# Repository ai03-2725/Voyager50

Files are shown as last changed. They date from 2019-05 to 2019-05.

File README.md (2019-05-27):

# Voyager50
A balance between function and size

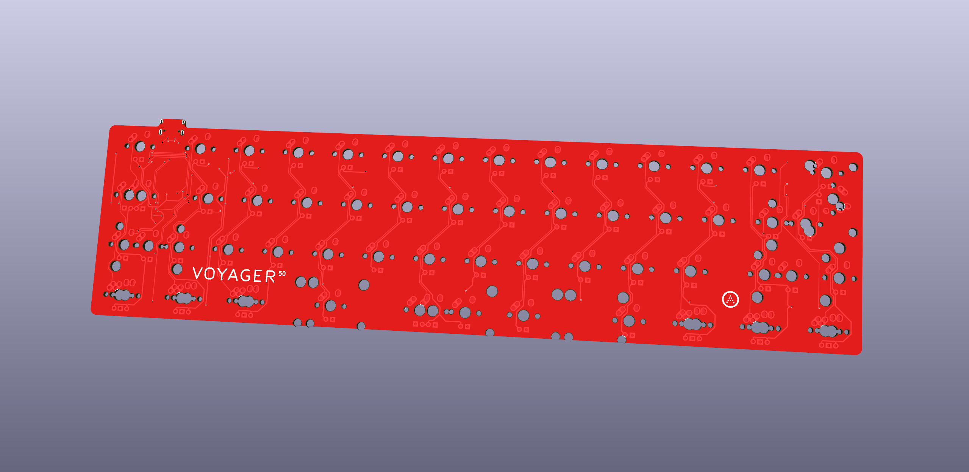
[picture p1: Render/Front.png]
Render


[Supported layouts](http://www.keyboard-layout-editor.com/#/gists/caf09ce52668a0b0574eaae53debacd4)  

#### In light of recent claims that I am 100% liable for any of my open source PCBs, I am adding this disclaimer.
#### I provide these PCBs as a reference for designing keyboard PCBs. Using them within your projects will require a will to do research of one's own and to learn the workings of them, potentially fixing issues if they exist.
# I provide these PCBs without liability and without any guarantees regarding functionality, as expressed in the MIT license under which all of these PCBs are licensed.

### Features
* In-switch LED backlighting
* RGB underglow
* Decent amount of layout compatibility
* Over-current and static discharge protection
* Fully open-source

### The Voyager PCB Family
The Voyager PCBs offer fully featured PCBs fit for any keyboard, whether mass production or high-end.

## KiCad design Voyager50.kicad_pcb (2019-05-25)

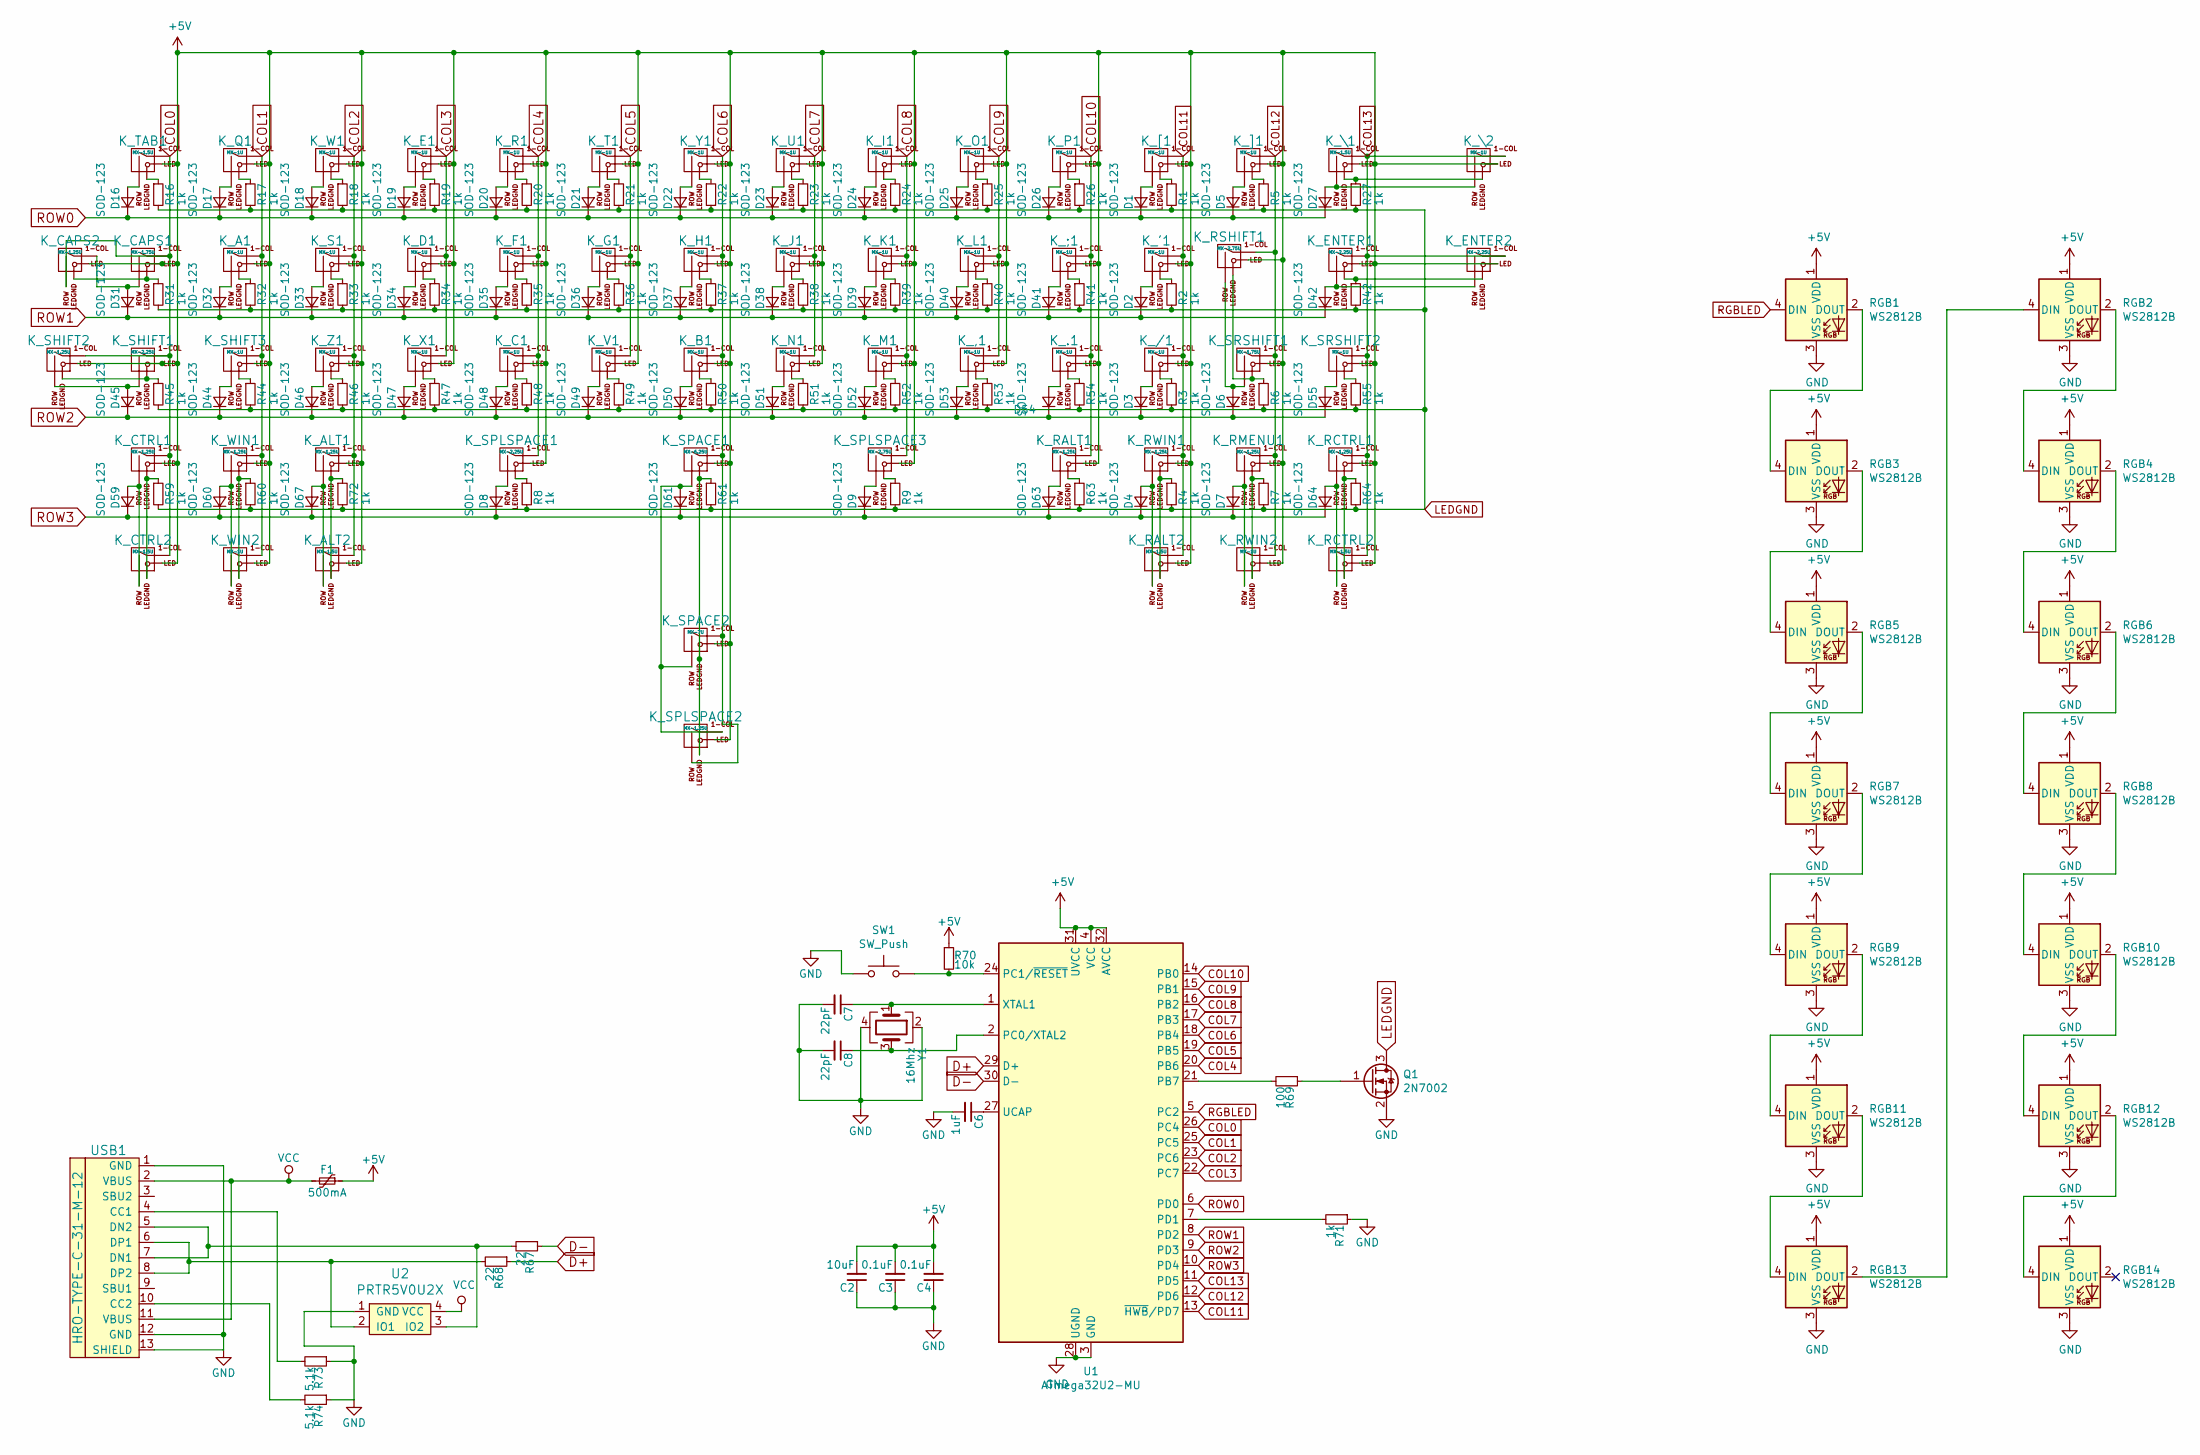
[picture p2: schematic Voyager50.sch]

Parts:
C2: 10uF; C_0603
C3, C4: 0.1uF; C_0603
C6: 1uF; C_0603
C7, C8: 22pF; C_0603
D1, D2, D3, D4, D5, D6, D7, D8, D9, D16, D17, D18, D19, D20, D21, D22, D23, D24, D25, D26, D27, D31, D32, D33, D34, D35, D36, D37, D38, D39, D40, D41, D42, D44, D45, D46, D47, D48, D49, D50, D51, D52, D53, D54, D55, D59, D60, D61, D63, D64, D67: SOD-123; D_SOD-123
F1: 500mA; Fuse_SMD1206_Reflow
K_'1: MX-1U
K_,1: MX-1U
K_.1: MX-1U
K_/1: MX-1U
K_;1: MX-1U
K_A1: MX-1U
K_ALT1: MX-1.25U
K_ALT2: MX-1.5U; MX-1.5U-FLIPPED
K_B1: MX-1U
K_C1: MX-1U
K_CAPS1: MX-1.75U
K_CAPS2: MX-1.25U; MX-1.25U-FLIPPED
K_CTRL1: MX-1.25U
K_CTRL2: MX-1.5U; MX-1.5U-FLIPPED
K_D1: MX-1U
K_E1: MX-1U
K_ENTER1: MX-2.25U
K_ENTER2: MX-2.25U; MX-ISO-ReversedStabilizers
K_F1: MX-1U
K_G1: MX-1U
K_H1: MX-1U
K_I1: MX-1U
K_J1: MX-1U
K_K1: MX-1U
K_L1: MX-1U
K_M1: MX-1U
K_N1: MX-1U
K_O1: MX-1U
K_P1: MX-1U
K_Q1: MX-1U
K_R1: MX-1U
K_RALT1: MX-1.25U
K_RALT2: MX-1.5U
K_RCTRL1: MX-1.25U; MX-1.25U-FLIPPED
K_RCTRL2: MX-1.5U
K_RMENU1: MX-1.25U; MX-1.25U-FLIPPED
K_RSHIFT1: MX-2.75U
K_RWIN1: MX-1.25U; MX-1.25U-FLIPPED
K_RWIN2: MX-1U
K_S1: MX-1U
K_SHIFT1: MX-2.25U
K_SHIFT2: MX-1.25U
K_SHIFT3: MX-1U
K_SPACE1: MX-6.25U; MX-6.25U-ReversedStabilizers
K_SPACE2: MX-7U; MX-7U-ReversedStabilizers
K_SPLSPACE1: MX-2.25U; MX-2.25U-ReversedStabilizers
K_SPLSPACE2: MX-1.25U; MX-1.25U-FLIPPED
K_SPLSPACE3: MX-2.75U; MX-2.75U-ReversedStabilizers
K_SRSHIFT1: MX-1.75U
K_SRSHIFT2: MX-1U
K_T1: MX-1U
K_TAB1: MX-1.5U
K_U1: MX-1U
K_V1: MX-1U
K_W1: MX-1U
K_WIN1: MX-1.25U
K_WIN2: MX-1U; MX-1U-FLIPPED
K_X1: MX-1U
K_Y1: MX-1U
K_Z1: MX-1U
K_[1: MX-1U
K_\1: MX-1.5U
K_\2: MX-1U
K_]1: MX-1U
Q1: 2N7002; SOT-23
R1, R2, R3, R4, R5, R6, R7, R8, R9, R16, R17, R18, R19, R20, R21, R22, R23, R24, R25, R26, R27, R31, R32, R33, R34, R35, R36, R37, R38, R39, R40, R41, R42, R44, R45, R46, R47, R48, R49, R50, R51, R52, R53, R54, R55, R59, R60, R61, R63, R64, R71, R72: 1k; R_0603
R67, R68: 22; R_0603
R69: 100; R_0603
R70: 10k; R_0603
R73, R74: 5.1k; R_0603
RGB1, RGB2, RGB3, RGB4, RGB5, RGB6, RGB7, RGB8, RGB9, RGB10, RGB11, RGB12, RGB13, RGB14: WS2812B; LED_WS2812B-PLCC4
SW1: SW_Push; SKQGADE010
U1: ATmega32U2-MU; QFN-32-1EP_5x5mm_Pitch0.5mm
U2: PRTR5V0U2X; SOT143B
USB1: HRO-TYPE-C-31-M-12; HRO-TYPE-C-31-M-12-Assembly
Y1: 16Mhz; Crystal_SMD_3225-4pin_3.2x2.5mm

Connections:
+5V: C2.2, C3.2, C4.2, F1.1, K_'1.3 (LED), K_,1.3 (LED), K_.1.3 (LED), K_/1.3 (LED), K_;1.3 (LED), K_A1.3 (LED), K_ALT1.3 (LED), K_ALT2.3 (LED), K_B1.3 (LED), K_C1.3 (LED), K_CAPS1.3 (LED), K_CAPS2.3 (LED), K_CTRL1.3 (LED), K_CTRL2.3 (LED), K_D1.3 (LED), K_E1.3 (LED), K_ENTER1.3 (LED), K_ENTER2.3 (LED), K_F1.3 (LED), K_G1.3 (LED), K_H1.3 (LED), K_I1.3 (LED), K_J1.3 (LED), K_K1.3 (LED), K_L1.3 (LED), K_M1.3 (LED), K_N1.3 (LED), K_O1.3 (LED), K_P1.3 (LED), K_Q1.3 (LED), K_R1.3 (LED), K_RALT1.3 (LED), K_RALT2.3 (LED), K_RCTRL1.3 (LED), K_RCTRL2.3 (LED), K_RMENU1.3 (LED), K_RSHIFT1.3 (LED), K_RWIN1.3 (LED), K_RWIN2.3 (LED), K_S1.3 (LED), K_SHIFT1.3 (LED), K_SHIFT2.3 (LED), K_SHIFT3.3 (LED), K_SPACE1.3 (LED), K_SPACE2.3 (LED), K_SPLSPACE1.3 (LED), K_SPLSPACE2.3 (LED), K_SPLSPACE3.3 (LED), K_SRSHIFT1.3 (LED), K_SRSHIFT2.3 (LED), K_T1.3 (LED), K_TAB1.3 (LED), K_U1.3 (LED), K_V1.3 (LED), K_W1.3 (LED), K_WIN1.3 (LED), K_WIN2.3 (LED), K_X1.3 (LED), K_Y1.3 (LED), K_Z1.3 (LED), K_[1.3 (LED), K_\1.3 (LED), K_\2.3 (LED), K_]1.3 (LED), R70.1, RGB1.1 (VDD), RGB2.1 (VDD), RGB3.1 (VDD), RGB4.1 (VDD), RGB5.1 (VDD), RGB6.1 (VDD), RGB7.1 (VDD), RGB8.1 (VDD), RGB9.1 (VDD), RGB10.1 (VDD), RGB11.1 (VDD), RGB12.1 (VDD), RGB13.1 (VDD), RGB14.1 (VDD), U1.4 (VCC), U1.31 (UVCC), U1.32 (AVCC)
COL0: K_CAPS1.1 (COL), K_CAPS2.2 (ROW), K_CTRL1.1 (COL), K_CTRL2.1 (COL), K_SHIFT1.1 (COL), K_SHIFT2.1 (COL), K_TAB1.1 (COL), U1.26 (PC4)
COL1: K_A1.1 (COL), K_Q1.1 (COL), K_SHIFT3.1 (COL), K_WIN1.1 (COL), K_WIN2.1 (COL), U1.25 (PC5)
COL2: K_ALT1.1 (COL), K_ALT2.1 (COL), K_S1.1 (COL), K_W1.1 (COL), K_Z1.1 (COL), U1.23 (PC6)
COL3: K_D1.1 (COL), K_E1.1 (COL), K_X1.1 (COL), U1.22 (PC7)
COL4: K_C1.1 (COL), K_F1.1 (COL), K_R1.1 (COL), K_SPLSPACE1.1 (COL), U1.20 (PB6)
COL5: K_G1.1 (COL), K_T1.1 (COL), K_V1.1 (COL), U1.19 (PB5)
COL6: K_B1.1 (COL), K_H1.1 (COL), K_SPACE1.1 (COL), K_SPACE2.1 (COL), K_SPLSPACE2.2 (ROW), K_Y1.1 (COL), U1.18 (PB4)
COL7: K_J1.1 (COL), K_N1.1 (COL), K_U1.1 (COL), U1.17 (PB3)
COL8: K_I1.1 (COL), K_K1.1 (COL), K_M1.1 (COL), K_SPLSPACE3.1 (COL), U1.16 (PB2)
COL9: K_,1.1 (COL), K_L1.1 (COL), K_O1.1 (COL), U1.15 (PB1)
COL10: K_.1.1 (COL), K_;1.1 (COL), K_P1.1 (COL), K_RALT1.1 (COL), U1.14 (PB0)
COL11: K_'1.1 (COL), K_/1.1 (COL), K_RALT2.1 (COL), K_RWIN1.1 (COL), K_[1.1 (COL), U1.13 (~HWB~/PD7)
COL12: K_RMENU1.1 (COL), K_RSHIFT1.1 (COL), K_RWIN2.1 (COL), K_SRSHIFT1.1 (COL), K_]1.1 (COL), U1.12 (PD6)
COL13: K_ENTER1.1 (COL), K_ENTER2.1 (COL), K_RCTRL1.1 (COL), K_RCTRL2.1 (COL), K_SRSHIFT2.1 (COL), K_\1.1 (COL), K_\2.1 (COL), U1.11 (PD5)
D+: R68.1, U1.29 (D+)
D-: R67.1, U1.30 (D-)
GND: C2.1, C3.1, C4.1, C6.2, C7.2, C8.2, Q1.2 (S), R71.1, R73.1, R74.1, RGB1.3 (VSS), RGB2.3 (VSS), RGB3.3 (VSS), RGB4.3 (VSS), RGB5.3 (VSS), RGB6.3 (VSS), RGB7.3 (VSS), RGB8.3 (VSS), RGB9.3 (VSS), RGB10.3 (VSS), RGB11.3 (VSS), RGB12.3 (VSS), RGB13.3 (VSS), RGB14.3 (VSS), SW1.1, U1.3 (GND), U1.28 (UGND), U1.33 (GND), U2.1 (GND), USB1.1 (GND), USB1.12 (GND), USB1.13 (SHIELD), Y1.2, Y1.4
LEDGND: Q1.3 (D), R1.2, R2.2, R3.2, R4.2, R5.2, R6.2, R7.2, R8.2, R9.2, R16.2, R17.2, R18.2, R19.2, R20.2, R21.2, R22.2, R23.2, R24.2, R25.2, R26.2, R27.2, R31.2, R32.2, R33.2, R34.2, R35.2, R36.2, R37.2, R38.2, R39.2, R40.2, R41.2, R42.2, R44.2, R45.2, R46.2, R47.2, R48.2, R49.2, R50.2, R51.2, R52.2, R53.2, R54.2, R55.2, R59.2, R60.2, R61.2, R63.2, R64.2, R72.2
unnamed: C6.1, U1.27 (UCAP)
unnamed: C7.1, U1.1 (XTAL1), Y1.1
unnamed: C8.1, U1.2 (PC0/XTAL2), Y1.3
unnamed: D1.2 (A), K_[1.2 (ROW)
unnamed: D2.2 (A), K_'1.2 (ROW)
unnamed: D3.2 (A), K_/1.2 (ROW)
unnamed: D4.2 (A), K_RALT2.2 (ROW), K_RWIN1.2 (ROW)
unnamed: D5.2 (A), K_]1.2 (ROW)
unnamed: D6.2 (A), K_RSHIFT1.2 (ROW), K_SRSHIFT1.2 (ROW)
unnamed: D7.2 (A), K_RMENU1.2 (ROW), K_RWIN2.2 (ROW)
unnamed: D8.2 (A), K_SPLSPACE1.2 (ROW)
unnamed: D9.2 (A), K_SPLSPACE3.2 (ROW)
unnamed: D16.2 (A), K_TAB1.2 (ROW)
unnamed: D17.2 (A), K_Q1.2 (ROW)
unnamed: D18.2 (A), K_W1.2 (ROW)
unnamed: D19.2 (A), K_E1.2 (ROW)
unnamed: D20.2 (A), K_R1.2 (ROW)
unnamed: D21.2 (A), K_T1.2 (ROW)
unnamed: D22.2 (A), K_Y1.2 (ROW)
unnamed: D23.2 (A), K_U1.2 (ROW)
unnamed: D24.2 (A), K_I1.2 (ROW)
unnamed: D25.2 (A), K_O1.2 (ROW)
unnamed: D26.2 (A), K_P1.2 (ROW)
unnamed: D27.2 (A), K_\1.2 (ROW), K_\2.2 (ROW)
unnamed: D31.2 (A), K_CAPS1.2 (ROW), K_CAPS2.1 (COL)
unnamed: D32.2 (A), K_A1.2 (ROW)
unnamed: D33.2 (A), K_S1.2 (ROW)
unnamed: D34.2 (A), K_D1.2 (ROW)
unnamed: D35.2 (A), K_F1.2 (ROW)
unnamed: D36.2 (A), K_G1.2 (ROW)
unnamed: D37.2 (A), K_H1.2 (ROW)
unnamed: D38.2 (A), K_J1.2 (ROW)
unnamed: D39.2 (A), K_K1.2 (ROW)
unnamed: D40.2 (A), K_L1.2 (ROW)
unnamed: D41.2 (A), K_;1.2 (ROW)
unnamed: D42.2 (A), K_ENTER1.2 (ROW), K_ENTER2.2 (ROW)
unnamed: D44.2 (A), K_SHIFT3.2 (ROW)
unnamed: D45.2 (A), K_SHIFT1.2 (ROW), K_SHIFT2.2 (ROW)
unnamed: D46.2 (A), K_Z1.2 (ROW)
unnamed: D47.2 (A), K_X1.2 (ROW)
unnamed: D48.2 (A), K_C1.2 (ROW)
unnamed: D49.2 (A), K_V1.2 (ROW)
unnamed: D50.2 (A), K_B1.2 (ROW)
unnamed: D51.2 (A), K_N1.2 (ROW)
unnamed: D52.2 (A), K_M1.2 (ROW)
unnamed: D53.2 (A), K_,1.2 (ROW)
unnamed: D54.2 (A), K_.1.2 (ROW)
unnamed: D55.2 (A), K_SRSHIFT2.2 (ROW)
unnamed: D59.2 (A), K_CTRL1.2 (ROW), K_CTRL2.2 (ROW)
unnamed: D60.2 (A), K_WIN1.2 (ROW), K_WIN2.2 (ROW)
unnamed: D61.2 (A), K_SPACE1.2 (ROW), K_SPACE2.2 (ROW), K_SPLSPACE2.1 (COL)
unnamed: D63.2 (A), K_RALT1.2 (ROW)
unnamed: D64.2 (A), K_RCTRL1.2 (ROW), K_RCTRL2.2 (ROW)
unnamed: D67.2 (A), K_ALT1.2 (ROW), K_ALT2.2 (ROW)
unnamed: K_'1.4 (LEDGND), R2.1
unnamed: K_,1.4 (LEDGND), R53.1
unnamed: K_.1.4 (LEDGND), R54.1
unnamed: K_/1.4 (LEDGND), R3.1
unnamed: K_;1.4 (LEDGND), R41.1
unnamed: K_A1.4 (LEDGND), R32.1
unnamed: K_ALT1.4 (LEDGND), K_ALT2.4 (LEDGND), R72.1
unnamed: K_B1.4 (LEDGND), R50.1
unnamed: K_C1.4 (LEDGND), R48.1
unnamed: K_CAPS1.4 (LEDGND), K_CAPS2.4 (LEDGND), R31.1
unnamed: K_CTRL1.4 (LEDGND), K_CTRL2.4 (LEDGND), R59.1
unnamed: K_D1.4 (LEDGND), R34.1
unnamed: K_E1.4 (LEDGND), R19.1
unnamed: K_ENTER1.4 (LEDGND), K_ENTER2.4 (LEDGND), R42.1
unnamed: K_F1.4 (LEDGND), R35.1
unnamed: K_G1.4 (LEDGND), R36.1
unnamed: K_H1.4 (LEDGND), R37.1
unnamed: K_I1.4 (LEDGND), R24.1
unnamed: K_J1.4 (LEDGND), R38.1
unnamed: K_K1.4 (LEDGND), R39.1
unnamed: K_L1.4 (LEDGND), R40.1
unnamed: K_M1.4 (LEDGND), R52.1
unnamed: K_N1.4 (LEDGND), R51.1
unnamed: K_O1.4 (LEDGND), R25.1
unnamed: K_P1.4 (LEDGND), R26.1
unnamed: K_Q1.4 (LEDGND), R17.1
unnamed: K_R1.4 (LEDGND), R20.1
unnamed: K_RALT1.4 (LEDGND), R63.1
unnamed: K_RALT2.4 (LEDGND), K_RWIN1.4 (LEDGND), R4.1
unnamed: K_RCTRL1.4 (LEDGND), K_RCTRL2.4 (LEDGND), R64.1
unnamed: K_RMENU1.4 (LEDGND), K_RWIN2.4 (LEDGND), R7.1
unnamed: K_RSHIFT1.4 (LEDGND), K_SRSHIFT1.4 (LEDGND), R6.1
unnamed: K_S1.4 (LEDGND), R33.1
unnamed: K_SHIFT1.4 (LEDGND), K_SHIFT2.4 (LEDGND), R45.1
unnamed: K_SHIFT3.4 (LEDGND), R44.1
unnamed: K_SPACE1.4 (LEDGND), K_SPACE2.4 (LEDGND), K_SPLSPACE2.4 (LEDGND), R61.1
unnamed: K_SPLSPACE1.4 (LEDGND), R8.1
unnamed: K_SPLSPACE3.4 (LEDGND), R9.1
unnamed: K_SRSHIFT2.4 (LEDGND), R55.1
unnamed: K_T1.4 (LEDGND), R21.1
unnamed: K_TAB1.4 (LEDGND), R16.1
unnamed: K_U1.4 (LEDGND), R23.1
unnamed: K_V1.4 (LEDGND), R49.1
unnamed: K_W1.4 (LEDGND), R18.1
unnamed: K_WIN1.4 (LEDGND), K_WIN2.4 (LEDGND), R60.1
unnamed: K_X1.4 (LEDGND), R47.1
unnamed: K_Y1.4 (LEDGND), R22.1
unnamed: K_Z1.4 (LEDGND), R46.1
unnamed: K_[1.4 (LEDGND), R1.1
unnamed: K_\1.4 (LEDGND), K_\2.4 (LEDGND), R27.1
unnamed: K_]1.4 (LEDGND), R5.1
unnamed: Q1.1 (G), R69.1
unnamed: R67.2, U2.3 (IO2), USB1.5 (DN2), USB1.7 (DN1)
unnamed: R68.2, U2.2 (IO1), USB1.6 (DP1), USB1.8 (DP2)
unnamed: R69.2, U1.21 (PB7)
unnamed: R70.2, SW1.2, U1.24 (PC1/~RESET)
unnamed: R71.2, U1.7 (PD1)
unnamed: R73.2, USB1.4 (CC1)
unnamed: R74.2, USB1.10 (CC2)
unnamed: RGB1.2 (DOUT), RGB3.4 (DIN)
unnamed: RGB2.2 (DOUT), RGB4.4 (DIN)
unnamed: RGB3.2 (DOUT), RGB5.4 (DIN)
unnamed: RGB4.2 (DOUT), RGB6.4 (DIN)
unnamed: RGB5.2 (DOUT), RGB7.4 (DIN)
unnamed: RGB6.2 (DOUT), RGB8.4 (DIN)
unnamed: RGB7.2 (DOUT), RGB9.4 (DIN)
unnamed: RGB10.2 (DOUT), RGB12.4 (DIN)
unnamed: RGB8.2 (DOUT), RGB10.4 (DIN)
unnamed: RGB11.2 (DOUT), RGB13.4 (DIN)
unnamed: RGB9.2 (DOUT), RGB11.4 (DIN)
unnamed: RGB12.2 (DOUT), RGB14.4 (DIN)
unnamed: RGB2.4 (DIN), RGB13.2 (DOUT)
RGBLED: RGB1.4 (DIN), U1.5 (PC2)
ROW0: D1.1 (K), D5.1 (K), D16.1 (K), D17.1 (K), D18.1 (K), D19.1 (K), D20.1 (K), D21.1 (K), D22.1 (K), D23.1 (K), D24.1 (K), D25.1 (K), D26.1 (K), D27.1 (K), U1.6 (PD0)
ROW1: D2.1 (K), D31.1 (K), D32.1 (K), D33.1 (K), D34.1 (K), D35.1 (K), D36.1 (K), D37.1 (K), D38.1 (K), D39.1 (K), D40.1 (K), D41.1 (K), D42.1 (K), U1.8 (PD2)
ROW2: D3.1 (K), D6.1 (K), D44.1 (K), D45.1 (K), D46.1 (K), D47.1 (K), D48.1 (K), D49.1 (K), D50.1 (K), D51.1 (K), D52.1 (K), D53.1 (K), D54.1 (K), D55.1 (K), U1.9 (PD3)
ROW3: D4.1 (K), D7.1 (K), D8.1 (K), D9.1 (K), D59.1 (K), D60.1 (K), D61.1 (K), D63.1 (K), D64.1 (K), D67.1 (K), U1.10 (PD4)
VCC: F1.2, U2.4 (VCC), USB1.2 (VBUS), USB1.11 (VBUS)

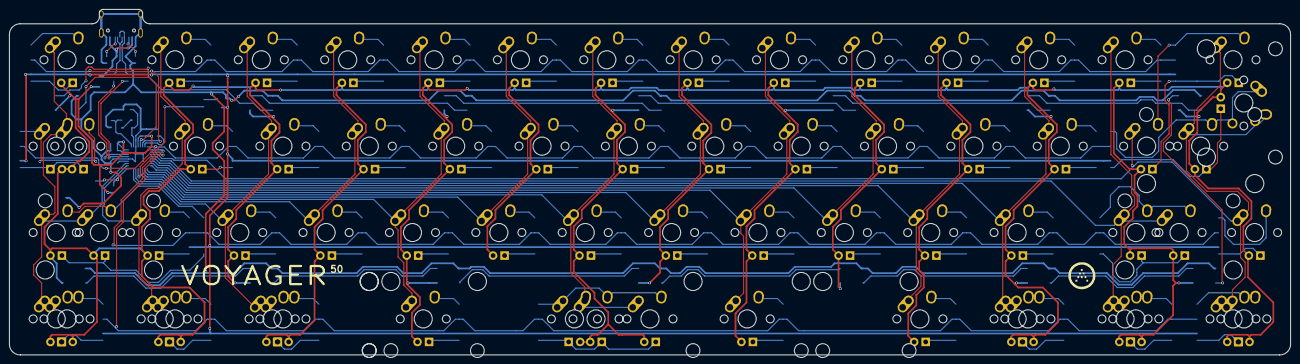
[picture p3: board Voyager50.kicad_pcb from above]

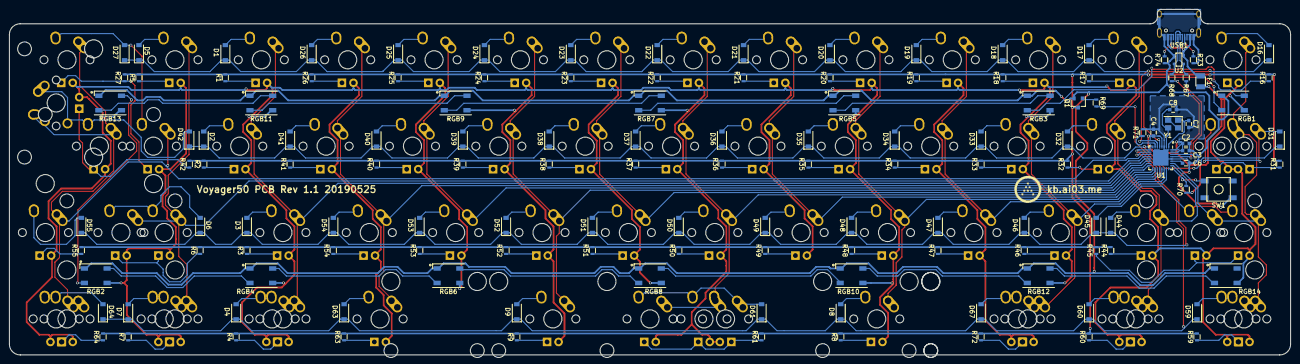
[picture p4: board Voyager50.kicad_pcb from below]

Board: 2 copper layers, 282.6 x 76.2 mm, 200 parts (136 on the bottom side), 151 nets.

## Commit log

2019-05-24 Populate base files
    [Voyager50.kicad_pcb, Voyager50.sch]
2019-05-25 Finish routing
    [Voyager50.kicad_pcb, Voyager50.sch]
2019-05-25 Update render, add gerbers
    [Voyager50-B_Cu.gbl, Voyager50-B_Mask.gbs, Voyager50-B_Paste.gbp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]
2019-05-25 Add split space
    [Voyager50-B_Cu.gbl, Voyager50-B_Mask.gbs, Voyager50-B_Paste.gbp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]
